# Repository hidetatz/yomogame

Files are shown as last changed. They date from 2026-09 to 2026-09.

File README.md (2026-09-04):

== Emulators & licensing

**NES** — `src/nes/` is copied and modified from
[`Esp32-S3-nes-emulator-by-DSN`](https://github.com/derdacavga/Esp32-S3-nes-emulator-by-DSN)
(imported at commit `030c4b8`), which is a fork of Nofrendo by Matthew Conte.
Some modifications are made (display/audio/ROM glue).

**Game Boy** — `src/gb/` bundles
[Peanut-GB](https://github.com/deltabeard/Peanut-GB) (`peanut_gb.h`) and its
`minigb_apu` APU library, unmodified except for a small include guard in
`minigb_apu.h`. DMG (original Game Boy) only; Game Boy Color games run in
grayscale where they run at all. `src/gb/gb_scene.h` and `src/gb/gb_core.c` are
first‑party glue.

== License

The upstream **NES** emulator code is licensed under the **GNU General Public
License v3** (see the `LICENSE` file, copied from the DSN repository; the
Nofrendo core originates as GPL‑licensed code by Matthew Conte). `src/nes/` in
this repository is a **derivative work** and remains under the GPL.

Peanut-GB and minigb_apu (`src/gb/`) are under the **MIT License** (see
`src/gb/peanut_gb.h` and `src/gb/LICENSE.minigb_apu`); their notices are retained.
MIT imposes no copyleft, but this code is combined into the same binary as the
GPL NES core, so the paragraph below applies to the whole firmware regardless.

Because the yomogame firmware links this GPL code into a single program,
**any distribution of a built yomogame binary (or of a device running it) is
subject to the GPL**: recipients must be able to obtain the complete
corresponding source code under the same terms. For that reason this repository
as a whole is distributed under **GPL‑3.0‑or‑later**.

The first‑party parts of this project (`lib/audio`, `lib/input`,
`lib/volume_overlay`, `src/tetris/`, `src/scene.h`, `src/frame_pusher.h`,
`src/yomogame.h`, `src/main.cpp`, `src/gb/gb_scene.h`, `src/gb/gb_core.c`) are
written by the yomogame author. They are released here under the GPL as part of
the combined work.

== Assets

Background music and sound effects are used courtesy of:

イワシロ音楽素材
https://iwashiro-sounds.work/

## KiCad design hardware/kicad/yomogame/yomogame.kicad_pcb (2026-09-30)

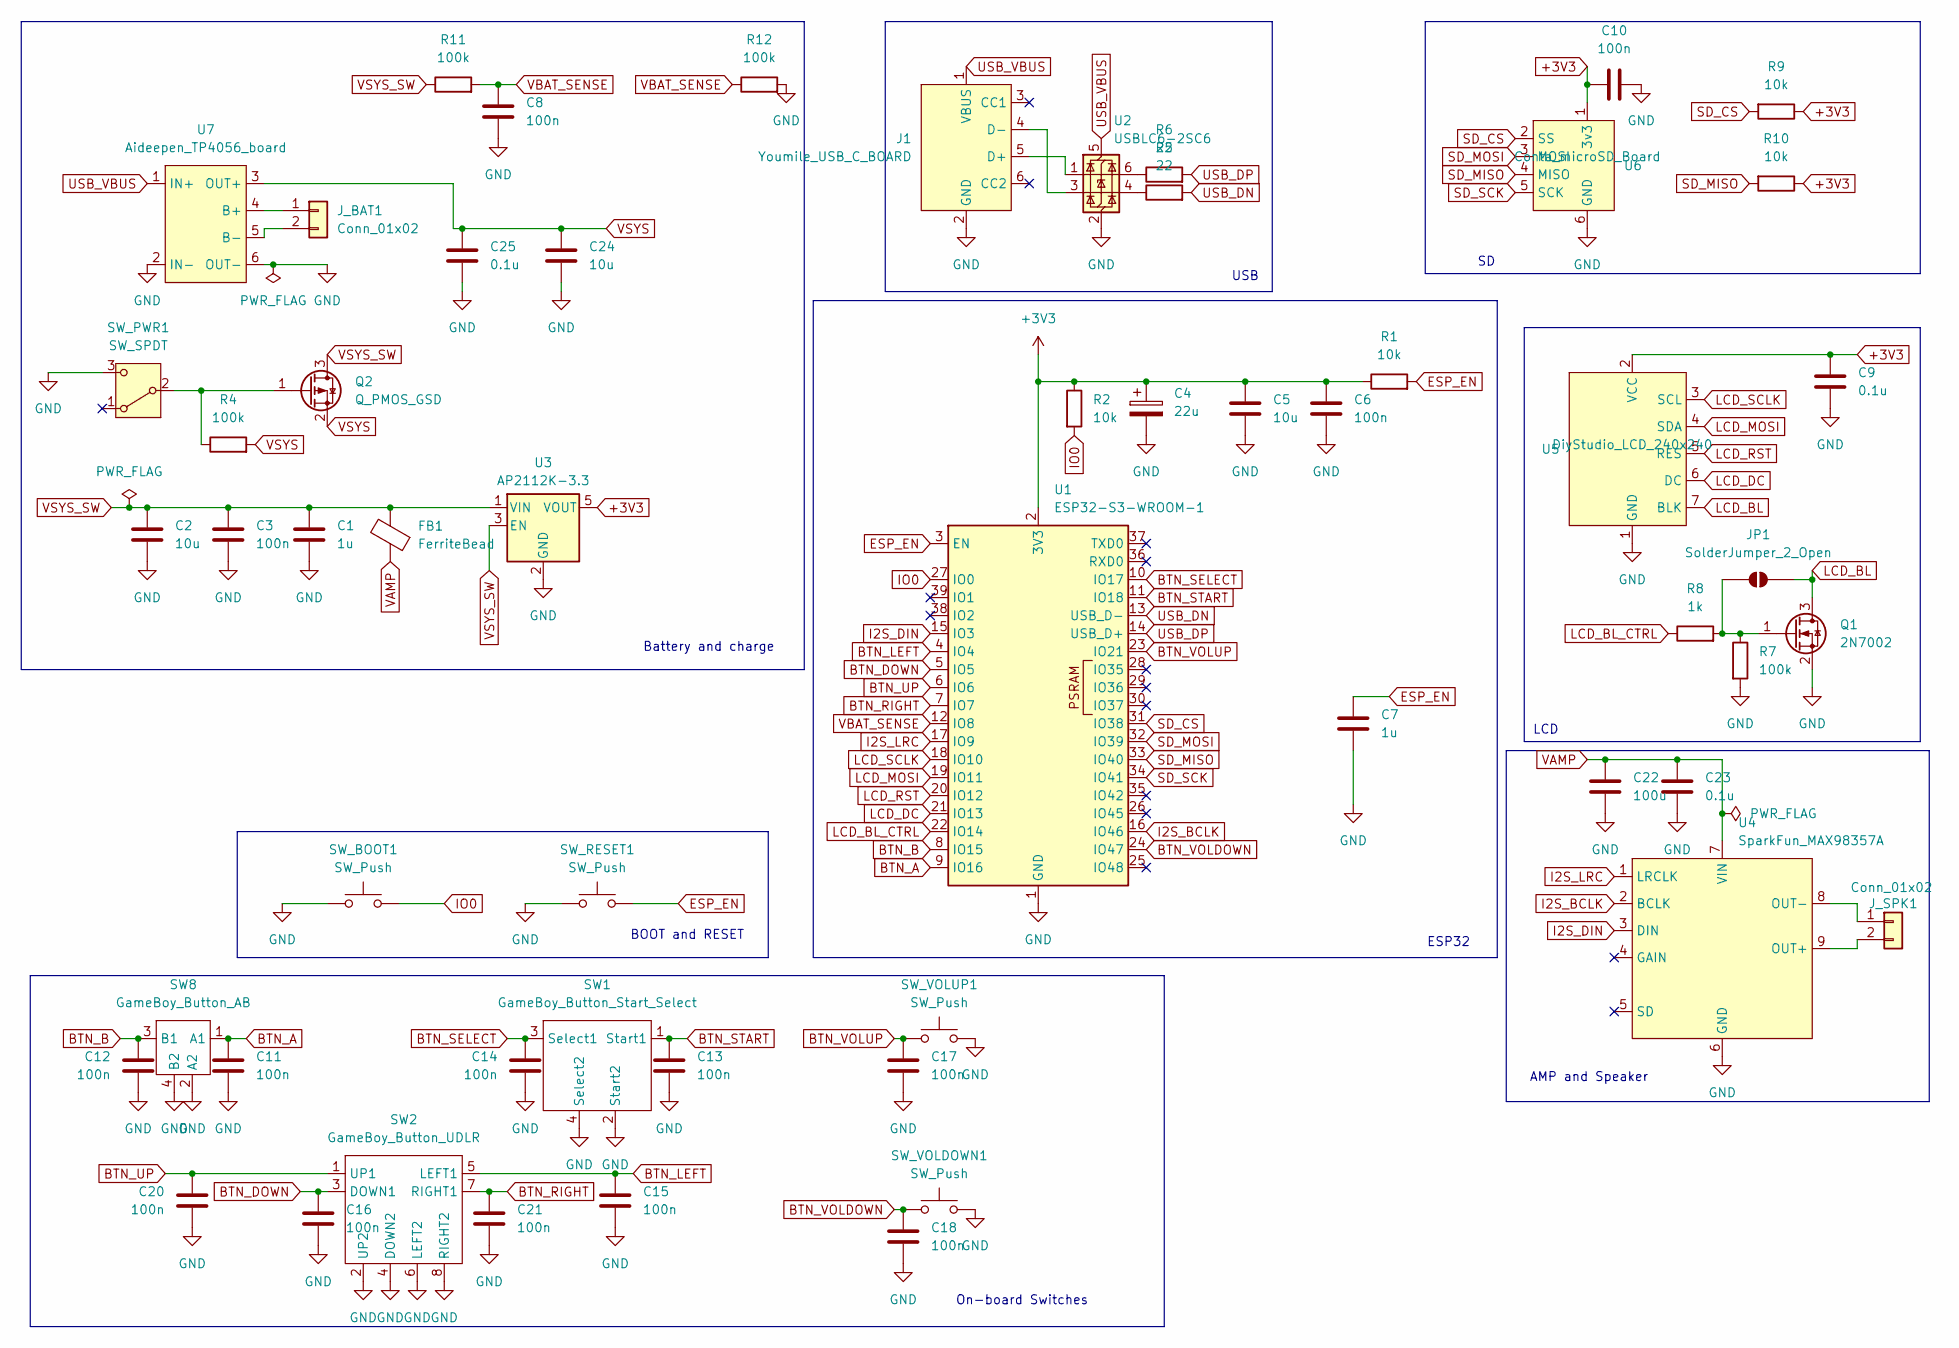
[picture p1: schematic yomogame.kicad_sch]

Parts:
C1, C7: 1u; C_0805_2012Metric_Pad1.18x1.45mm_HandSolder
C2, C5, C24: 10u; C_0805_2012Metric_Pad1.18x1.45mm_HandSolder
C3, C6, C8, C10, C11, C12, C13, C14, C15, C16, C17, C18, C20, C21: 100n; C_0805_2012Metric_Pad1.18x1.45mm_HandSolder
C4: 22u; C_1206_3216Metric_Pad1.33x1.80mm_HandSolder
C9, C23, C25: 0.1u; C_0805_2012Metric_Pad1.18x1.45mm_HandSolder
C22: 100u; CP_Radial_D5.0mm_P2.50mm
FB1: FerriteBead; L_0805_2012Metric_Pad1.05x1.20mm_HandSolder
J1: Youmile_USB_C_BOARD
JP1: SolderJumper_2_Open; SolderJumper-2_P1.3mm_Open_Pad1.0x1.5mm
J_BAT1: Conn_01x02; JST_PH_B2B-PH-K_1x02_P2.00mm_Vertical
J_SPK1: Conn_01x02; JST_PH_B2B-PH-K_1x02_P2.00mm_Vertical
Q1: 2N7002; SOT-23_Handsoldering
Q2: Q_PMOS_GSD; SOT-23_Handsoldering
R1, R2, R9, R10: 10k; R_0805_2012Metric_Pad1.20x1.40mm_HandSolder
R4, R7, R11, R12: 100k; R_0805_2012Metric_Pad1.20x1.40mm_HandSolder
R5, R6: 22; R_0805_2012Metric_Pad1.20x1.40mm_HandSolder
R8: 1k; R_0805_2012Metric_Pad1.20x1.40mm_HandSolder
SW1: GameBoy_Button_Start_Select; BTN_start_select
SW2: GameBoy_Button_UDLR; BTN_UDLR
SW8: GameBoy_Button_AB; BTN_AB
SW_BOOT1: SW_Push; SW_PUSH_6mm
SW_PWR1: SW_SPDT; SW_Slide_SPDT_SK-12D11VG3
SW_RESET1: SW_Push; SW_PUSH_6mm
SW_VOLDOWN1: SW_Push; SW_SMD_Side_THAU13-AB-R
SW_VOLUP1: SW_Push; SW_SMD_Side_THAU13-AB-R
U1: ESP32-S3-WROOM-1
U2: USBLC6-2SC6; SOT-23-6_Handsoldering
U3: AP2112K-3.3; SOT-23-5_HandSoldering
U4: SparkFun_MAX98357A; AMP_SparkFun_MAX98357A_I2S_AUDIO
U5: DiyStudio_LCD_240x240
U6: Conta_microSD_Board
U7: Aideepen_TP4056_board

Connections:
+3V3: C4.1, C5.1, C6.1, C9.1, C10.1, R1.1, R2.1, R9.1, R10.1, U1.2 (3V3), U3.5 (VOUT), U5.2 (VCC), U6.1 (3v3)
BTN_A: C11.1, SW8.1 (A1), U1.9 (IO16)
BTN_B: C12.1, SW8.3 (B1), U1.8 (IO15)
BTN_DOWN: C16.1, SW2.3 (DOWN1), U1.5 (IO5)
BTN_LEFT: C15.1, SW2.5 (LEFT1), U1.4 (IO4)
BTN_RIGHT: C21.1, SW2.7 (RIGHT1), U1.7 (IO7)
BTN_SELECT: C14.1, SW1.3 (Select1), U1.10 (IO17)
BTN_START: C13.1, SW1.1 (Start1), U1.11 (IO18)
BTN_UP: C20.1, SW2.1 (UP1), U1.6 (IO6)
BTN_VOLDOWN: C18.1, SW_VOLDOWN1.1, U1.24 (IO47)
BTN_VOLUP: C17.1, SW_VOLUP1.1, U1.23 (IO21)
ESP_EN: C7.1, R1.2, SW_RESET1.2, U1.3 (EN)
GND: C1.2, C2.2, C3.2, C4.2, C5.2, C6.2, C7.2, C8.2, C9.2, C10.2, C11.2, C12.2, C13.2, C14.2, C15.2, C16.2, C17.2, C18.2, C20.2, C21.2, C22.2, C23.2, C24.2, C25.2, J1.2 (GND), Q1.2 (S), R7.2, R12.2, SW1.2 (Start2), SW1.4 (Select2), SW2.2 (UP2), SW2.4 (DOWN2), SW2.6 (LEFT2), SW2.8 (RIGHT2), SW8.2 (A2), SW8.4 (B2), SW_BOOT1.1, SW_PWR1.3 (C), SW_RESET1.1, SW_VOLDOWN1.2, SW_VOLUP1.2, U1.1 (GND), U1.40 (GND), U1.41 (GND), U2.2 (GND), U3.2 (GND), U4.6 (GND), U5.1 (GND), U6.6 (GND), U7.2 (IN-), U7.6 (OUT-)
I2S_BCLK: U1.16 (IO46), U4.2 (BCLK)
I2S_DIN: U1.15 (IO3), U4.3 (DIN)
I2S_LRC: U1.17 (IO9), U4.1 (LRCLK)
IO0: R2.2, SW_BOOT1.2, U1.27 (IO0)
LCD_BL: JP1.2 (B), Q1.3 (D), U5.7 (BLK)
LCD_BL_CTRL: R8.1, U1.22 (IO14)
LCD_DC: U1.21 (IO13), U5.6 (DC)
LCD_MOSI: U1.19 (IO11), U5.4 (SDA)
LCD_RST: U1.20 (IO12), U5.5 (RES)
LCD_SCLK: U1.18 (IO10), U5.3 (SCL)
unnamed: J1.5 (D+), U2.1 (I/O1)
unnamed: J1.4 (D-), U2.3 (I/O2)
unnamed: JP1.1 (A), Q1.1 (G), R7.1, R8.2
unnamed: J_BAT1.1, U7.4 (B+)
unnamed: J_BAT1.2, U7.5 (B-)
unnamed: J_SPK1.1, U4.8 (OUT-)
unnamed: J_SPK1.2, U4.9 (OUT+)
unnamed: Q2.1 (G), R4.1, SW_PWR1.2 (B)
unnamed: R5.1, U2.4 (I/O2)
unnamed: R6.1, U2.6 (I/O1)
SD_CS: R9.2, U1.31 (IO38), U6.2 (SS)
SD_MISO: R10.2, U1.33 (IO40), U6.4 (MISO)
SD_MOSI: U1.32 (IO39), U6.3 (MOSI)
SD_SCK: U1.34 (IO41), U6.5 (SCK)
USB_DN: R5.2, U1.13 (USB_D-)
USB_DP: R6.2, U1.14 (USB_D+)
USB_VBUS: J1.1 (VBUS), U2.5 (VBUS), U7.1 (IN+)
VAMP: C22.1, C23.1, FB1.1, U4.7 (VIN)
VBAT_SENSE: C8.1, R11.2, R12.1, U1.12 (IO8)
VSYS: C24.1, C25.1, Q2.2 (S), R4.2, U7.3 (OUT+)
VSYS_SW: C1.1, C2.1, C3.1, FB1.2, Q2.3 (D), R11.1, U3.1 (VIN), U3.3 (EN)

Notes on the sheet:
On-board Switches
ESP32
BOOT and RESET
AMP and Speaker
Battery and charge
LCD
USB

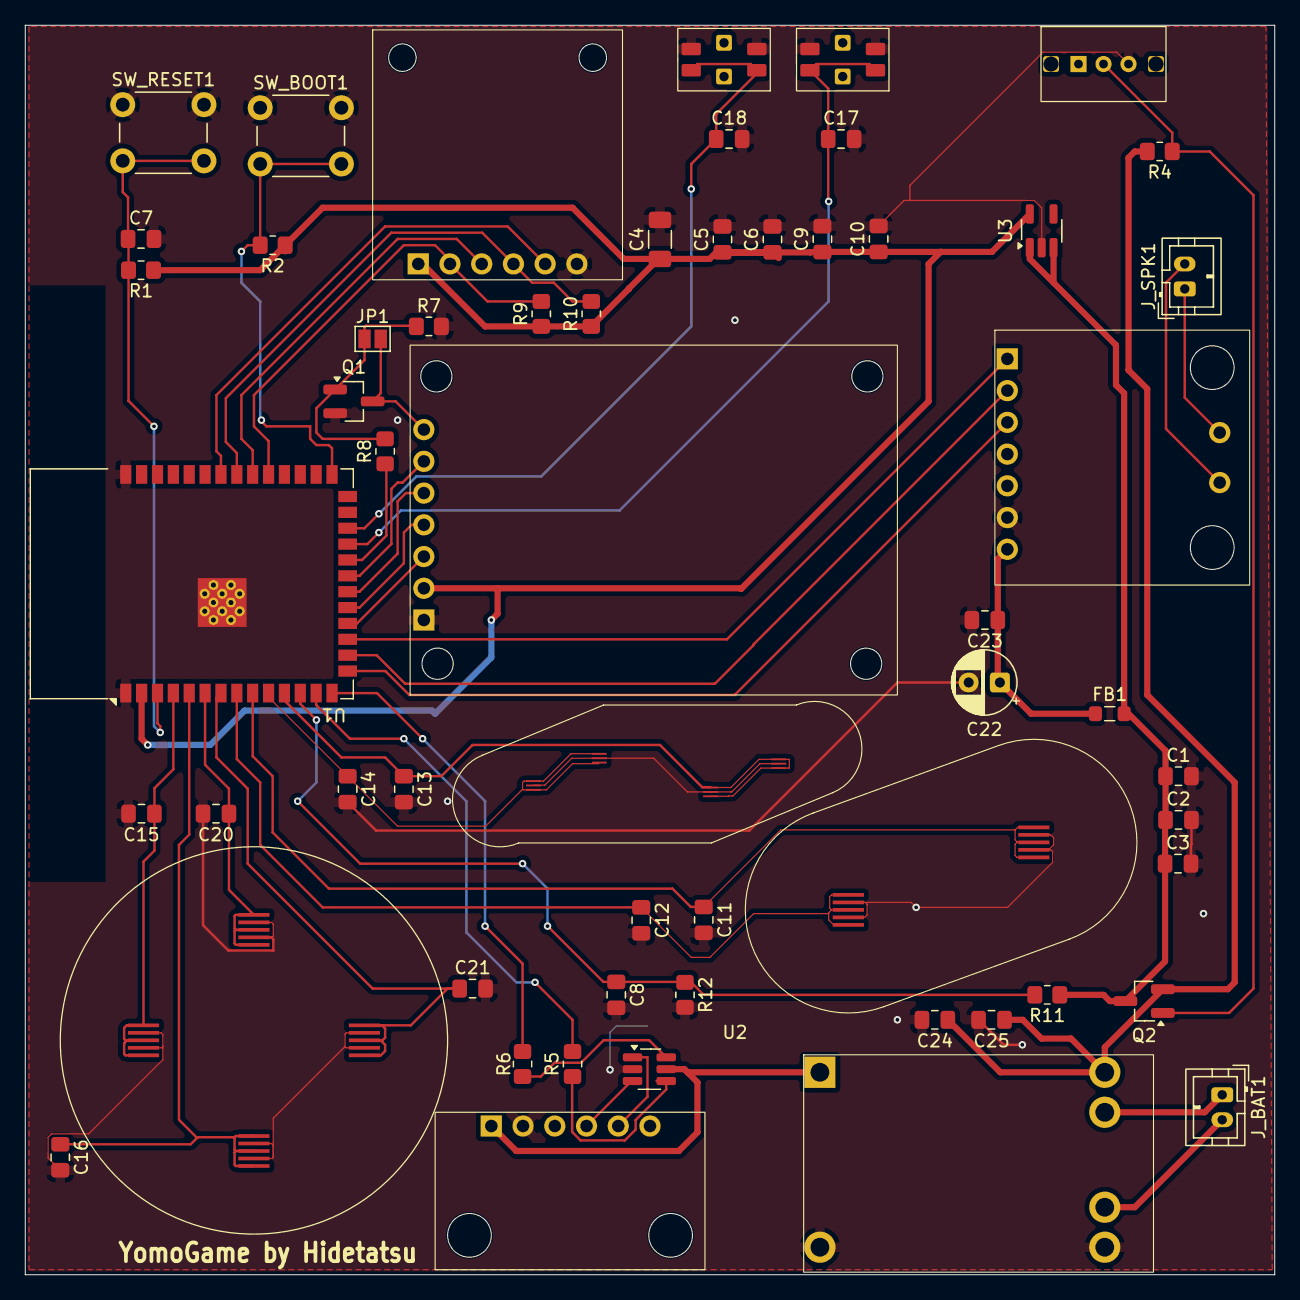
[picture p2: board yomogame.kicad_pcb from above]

Board: 2 copper layers, 100.0 x 100.0 mm, 57 parts (0 on the bottom side), 44 nets.

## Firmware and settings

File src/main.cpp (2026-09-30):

#include <Arduino.h>
#include <SPI.h>
#include <TFT_eSPI.h>
#include <esp_system.h>

#include <audio.h>
#include <input.h>

#include "yomogame.h"

// Pin assignments, sourced from the yomogame custom PCB schematic
// (hardware/kicad/yomogame/yomogame.kicad_sch). GPIO0 (BOOT), EN, USB_D-/D+
// (native USB) and GPIO35-37 (octal PSRAM) are wired on the board but are not
// application GPIOs, so they don't appear below.

const int btnA = 16;
const int btnB = 15;
const int btnStart = 18;
const int btnSelect = 17;
const int btnRight = 7;
const int btnUp = 6;
const int btnDown = 5;
const int btnLeft = 4;
const int btnVolUp = 21;
const int btnVolDown = 47;

const int pinI2SBCLK = 46;
const int pinI2SLRC = 9;
const int pinI2SDIN = 3;

// LCD (TFT_eSPI) and SD pins are set via platformio.ini build_flags and
// src/nes/hw_config.h respectively, both cross-checked against the same
// schematic. Battery voltage (VBAT_SENSE, GPIO8) is read directly in
// yomogame.h's BatteryIndicator, next to the UI that displays it.

void setup() {
  // serial setting
  Serial.begin(115200);
  Serial.printf("Reset reason: %d\n", esp_reset_reason());

  // screen setting
  static TFT_eSPI screen;
  screen.init();
  digitalWrite(TFT_BL, LOW); // hide stale GRAM contents until cleared below
  screen.setRotation(1);
  screen.fillScreen(TFT_BLACK);
  digitalWrite(TFT_BL, HIGH);

  static input::Buttons buttons(btnA, btnB, btnStart, btnSelect, btnRight, btnUp, btnDown, btnLeft);
  static input::VolumeButtons volume_buttons(btnVolUp, btnVolDown);
  static audio::Audio audio(pinI2SBCLK, pinI2SLRC, pinI2SDIN, volume_buttons);

  static yomogame::MainLoop mainloop(screen, audio, buttons);
  mainloop.run(); // never returns
}

void loop() {
  while (true) delay(100);
}

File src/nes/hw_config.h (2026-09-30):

#pragma once

#include <SPI.h>

// The DSN emulator's compile-time sound path (built-in i2s_driver_install) is
// disabled: audio is bridged into audio::Audio via nes_audio_push() instead.
#define ENABLE_SOUND 0

// SD card has its own dedicated SPI bus on this board, separate from the LCD
// (TFT_eSPI owns the other hardware SPI peripheral via TFT_SCLK/TFT_MOSI).
#define SD_CS   38
#define SD_MISO 40
#define SD_SCK  41
#define SD_MOSI 39

// Lazily-initialised SPI bus for the SD card. Shared by nes_scene.h and
// gb_scene.h (whichever scene runs first performs the one-time begin()).
inline SPIClass& sd_spi_bus() {
  static SPIClass bus(HSPI);
  static bool started = false;
  if (!started) {
    bus.begin(SD_SCK, SD_MISO, SD_MOSI, SD_CS);
    started = true;
  }
  return bus;
}

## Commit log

2026-08-27 use disp param in stats, board
2026-09-04 Revert "structure change: loop on main"
    This reverts commit 09c0ccb914a10cdbb0a23a7499d3701d5bb25b14.
    [main.cpp, yomogame.h]
